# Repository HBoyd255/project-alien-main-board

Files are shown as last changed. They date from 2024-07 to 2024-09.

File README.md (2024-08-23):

# Project A.L.I.E.N. Main Board

<!-- Harry Boyd - hboyd255@gmail.com - 22/07/2024 -->

This is the repository for the main board of Project A.L.I.E.N. (Autonomous
Labyrinth Investigator, Explorer, Navigator).

This project started as a University project for the module
[Robotics Design and Construction](https://www.york.ac.uk/students/studying/manage/programmes/module-catalogue/module/ELE00098H).
To get us started, the University provided us with a main board, called the ARB
(Arduino Robotics Board), which was designed to break out the pins of an Arduino
Nano 33 BLE into connectors that were easier to use. However, when the module
concluded, the University wanted the boards back, so I designed my own.

## Testing

The code to test the board has been split into separate repositories.

- [Motors and Encoders](https://github.com/HBoyd255/project-alien-motor-test-code)
- [Bumper and NES Shift Registers](https://github.com/HBoyd255/project-alien-shift-register-test-code)
- [LED Strip and Level Shifter](https://github.com/HBoyd255/project-alien-led-strip-test-code)
- [Ultrasonic Sensor](https://github.com/HBoyd255/project-alien-ultrasonic-test-code)
- [Infrared Sensors and I2C Multiplexer](https://github.com/HBoyd255/project-alien-infrared-test-code)

## Expansion Boards

The Project A.L.I.E.N. Main Board has been designed to to take expansion boards.
This utilises the 3 left-over GPIO pins, D11, D12 and D13.

- [Extra buttons ](https://github.com/HBoyd255/project-alien-expansion-demo-buttons)

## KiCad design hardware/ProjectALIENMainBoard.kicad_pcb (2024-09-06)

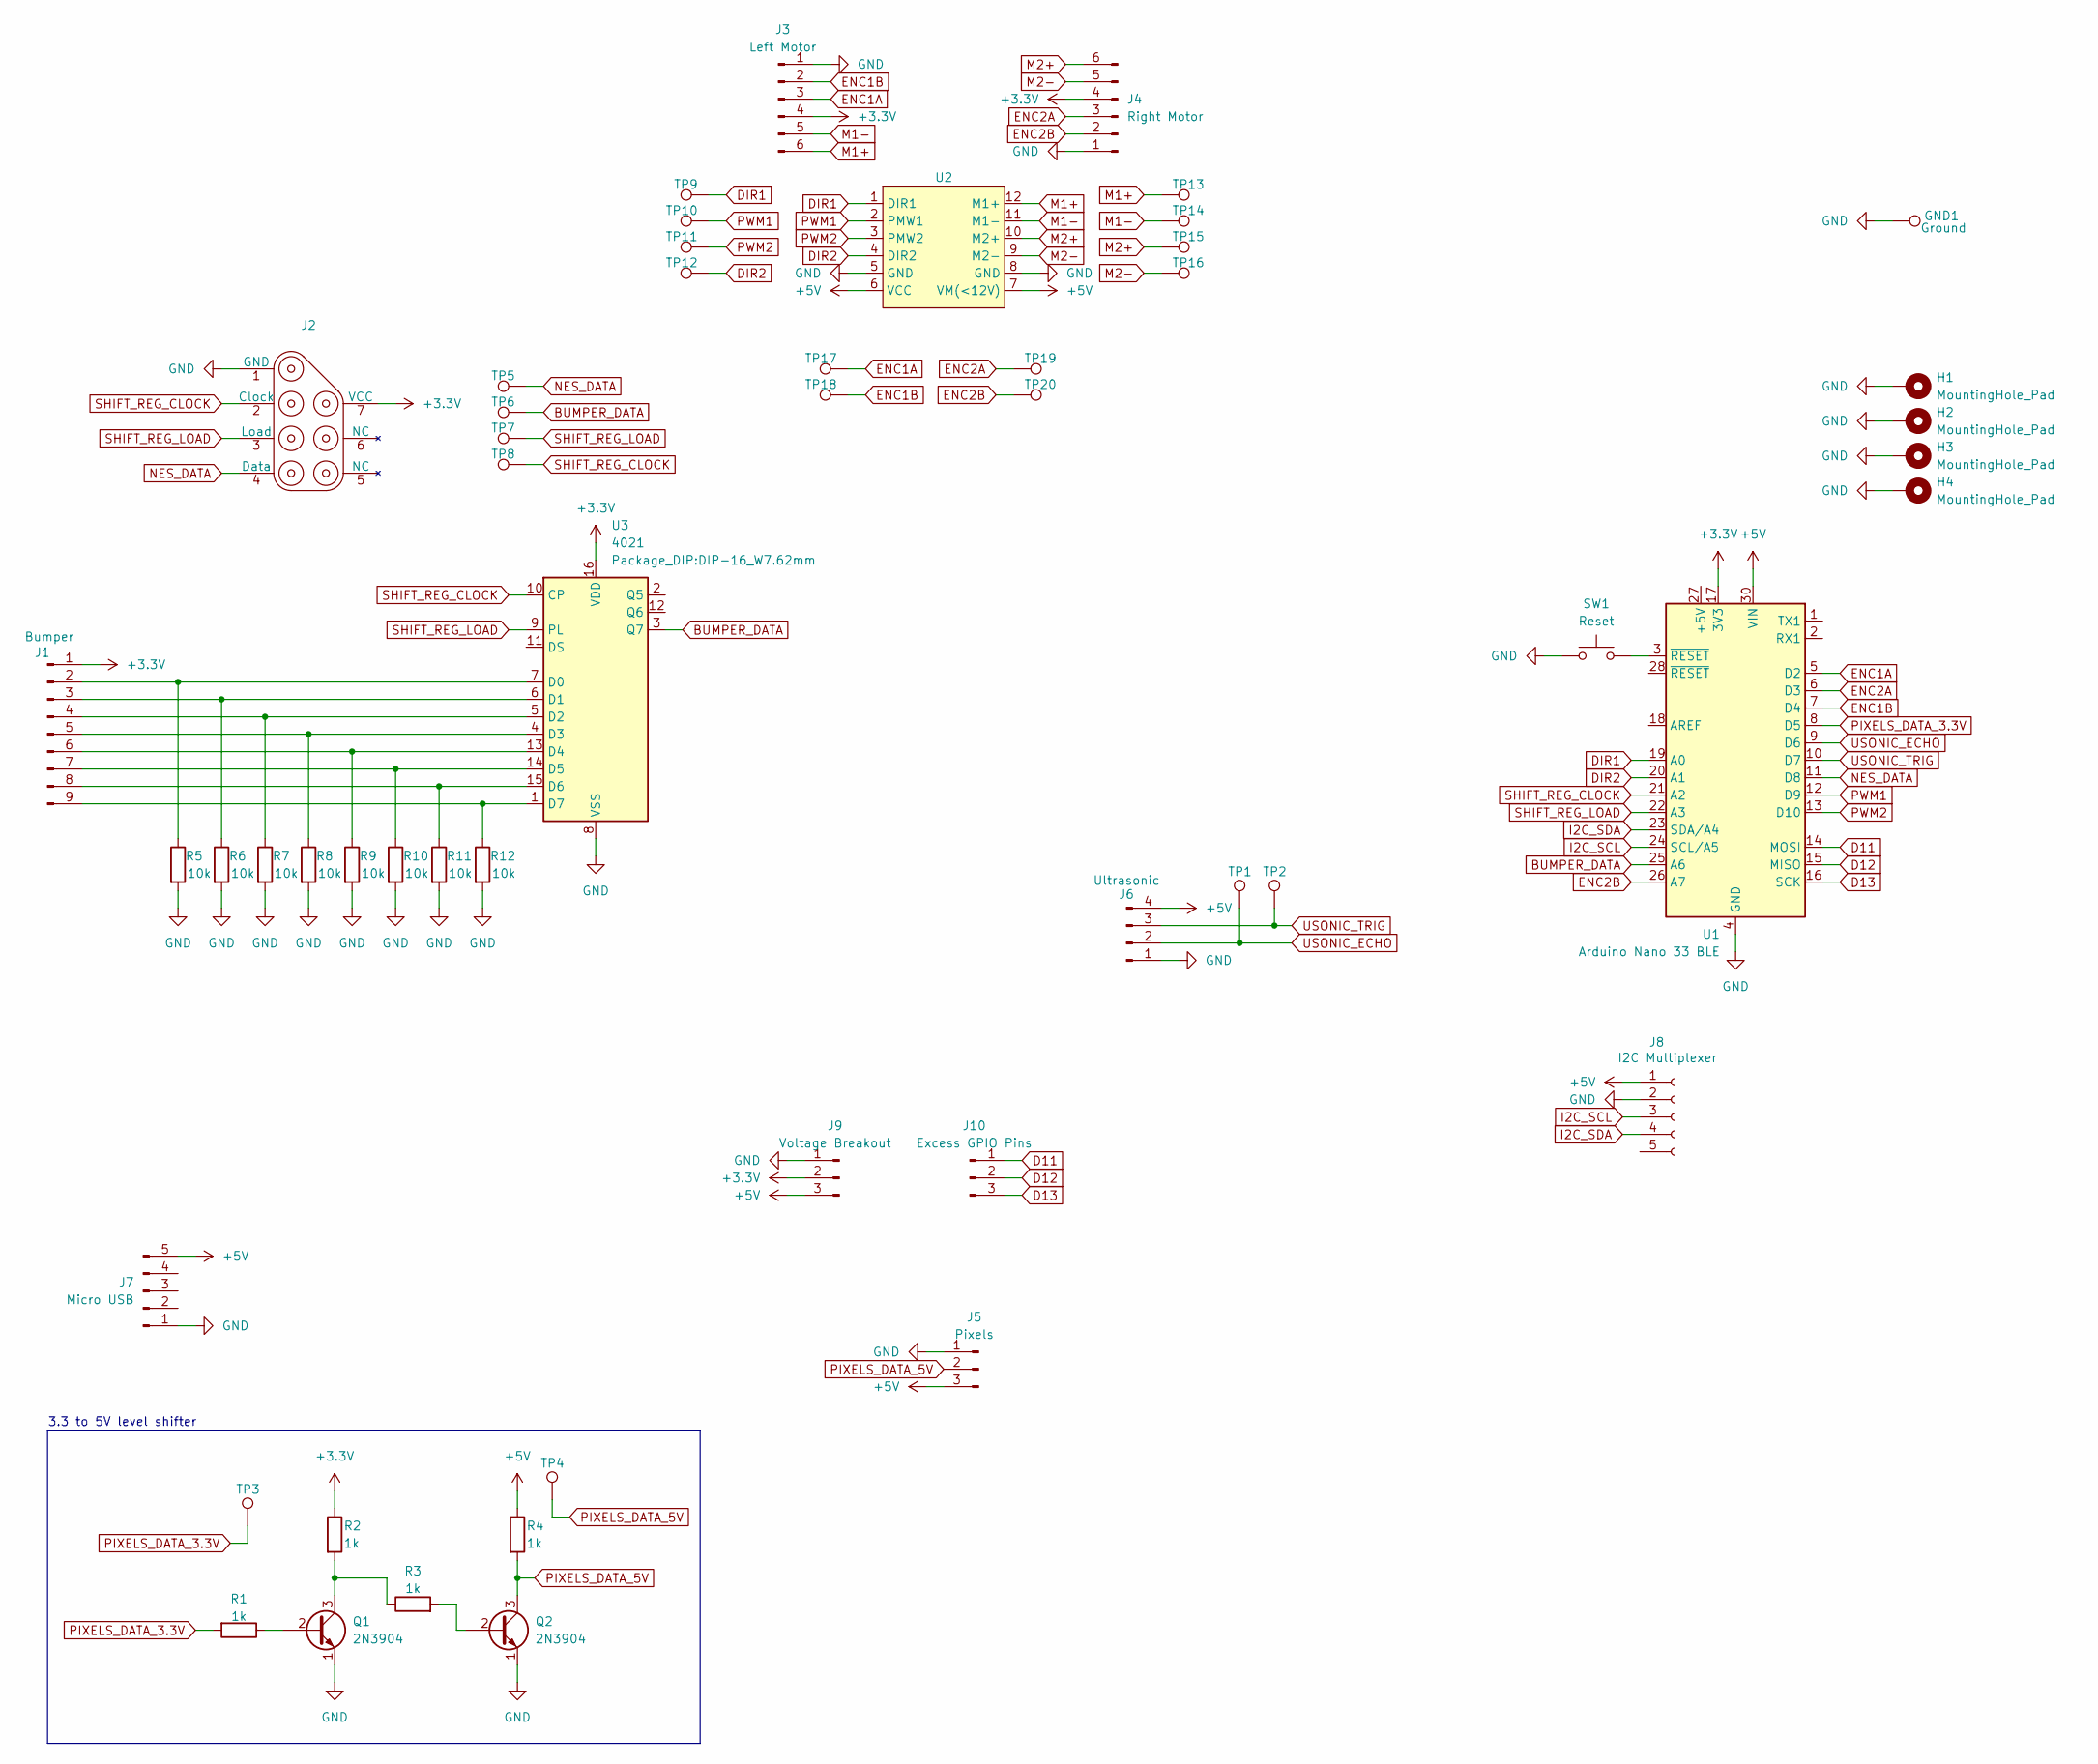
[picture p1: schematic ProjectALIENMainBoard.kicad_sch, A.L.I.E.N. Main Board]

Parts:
GND1: Ground; TestPoint_Bridge_Pitch2.54mm_Drill0.7mm
H1, H2, H3, H4: MountingHole_Pad; MountingHole_2.7mm_M2.5_Pad
J1: Bumper; PinHeader_1x09_P2.54mm_Horizontal
J2: NES_Controller_Port
J3: Left Motor; PinHeader_1x06_P2.54mm_Horizontal
J4: Right Motor; PinHeader_1x06_P2.54mm_Horizontal
J5: Pixels; PinHeader_1x03_P2.54mm_Vertical
J6: Ultrasonic; PinHeader_1x04_P2.54mm_Horizontal
J7: Micro USB; Adafruit_1833_Shield
J8: I2C Multiplexer; Adafruit_5664_Shield
J9: Voltage Breakout; PinHeader_1x03_P2.54mm_Vertical
J10: Excess GPIO Pins; PinHeader_1x03_P2.54mm_Vertical
Q1, Q2: 2N3904; TO-92_Inline
R1, R2, R3, R4: 1k; R_0402_1005Metric_Pad0.72x0.64mm_HandSolder
R5, R6, R7, R8, R9, R10, R11, R12: 10k; R_0402_1005Metric_Pad0.72x0.64mm_HandSolder
SW1: Reset; Two_Pin_Through_Hole_Push_Button
TP1, TP2, TP3, TP4, TP5, TP6, TP7, TP8, TP9, TP10, TP11, TP12, TP13, TP14, TP15, TP16, TP17, TP18, TP19, TP20: TestPoint; TestPoint_THTPad_D1.0mm_Drill0.5mm
U1: Arduino Nano 33 BLE; Arduino_Nano
U2: DFRobot_DC_Motor_Driver_Shield
U3: 4021; DIP-16_W7.62mm

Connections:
+3.3V: J1.1, J2.7 (VCC), J3.4, J4.4, J9.2, R2.1, U1.17 (3V3), U3.16 (VDD)
+5V: J5.3, J6.4, J7.5, J8.1, J9.3, R4.1, U1.30 (VIN), U2.6 (VCC), U2.7 (VM(<12V))
BUMPER_DATA: TP6.1, U1.25 (A6), U3.3 (Q7)
D11: J10.1, U1.14 (MOSI)
D12: J10.2, U1.15 (MISO)
D13: J10.3, U1.16 (SCK)
DIR1: TP9.1, U1.19 (A0), U2.1 (DIR1)
DIR2: TP12.1, U1.20 (A1), U2.4 (DIR2)
ENC1A: J3.3, TP17.1, U1.5 (D2)
ENC1B: J3.2, TP18.1, U1.7 (D4)
ENC2A: J4.3, TP19.1, U1.6 (D3)
ENC2B: J4.2, TP20.1, U1.26 (A7)
GND: GND1.1, H1.1, H2.1, H3.1, H4.1, J2.1 (GND), J3.1, J4.1, J5.1, J6.1, J7.1, J8.2, J9.1, Q1.1 (E), Q2.1 (E), R5.2, R6.2, R7.2, R8.2, R9.2, R10.2, R11.2, R12.2, SW1.1, U1.4 (GND), U1.29 (GND), U2.5 (GND), U2.8 (GND), U3.8 (VSS)
I2C_SCL: J8.3, U1.24 (SCL/A5)
I2C_SDA: J8.4, U1.23 (SDA/A4)
M1+: J3.6, TP13.1, U2.12 (M1+)
M1-: J3.5, TP14.1, U2.11 (M1-)
M2+: J4.6, TP15.1, U2.10 (M2+)
M2-: J4.5, TP16.1, U2.9 (M2-)
NES_DATA: J2.4 (Data), TP5.1, U1.11 (D8)
unnamed: J1.2, R5.1, U3.7 (D0)
unnamed: J1.3, R6.1, U3.6 (D1)
unnamed: J1.4, R7.1, U3.5 (D2)
unnamed: J1.5, R8.1, U3.4 (D3)
unnamed: J1.6, R9.1, U3.13 (D4)
unnamed: J1.7, R10.1, U3.14 (D5)
unnamed: J1.8, R11.1, U3.15 (D6)
unnamed: J1.9, R12.1, U3.1 (D7)
unnamed: Q1.2 (B), R1.1
unnamed: Q1.3 (C), R2.2, R3.1
unnamed: Q2.2 (B), R3.2
unnamed: SW1.2, U1.3 (~RESET)
PIXELS_DATA_3.3V: R1.2, TP3.1, U1.8 (D5)
PIXELS_DATA_5V: J5.2, Q2.3 (C), R4.2, TP4.1
PWM1: TP10.1, U1.12 (D9), U2.2 (PMW1)
PWM2: TP11.1, U1.13 (D10), U2.3 (PMW2)
SHIFT_REG_CLOCK: J2.2 (Clock), TP8.1, U1.21 (A2), U3.10 (CP)
SHIFT_REG_LOAD: J2.3 (Load), TP7.1, U1.22 (A3), U3.9 (PL)
USONIC_ECHO: J6.2, TP1.1, U1.9 (D6)
USONIC_TRIG: J6.3, TP2.1, U1.10 (D7)

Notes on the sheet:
3.3 to 5V level shifter

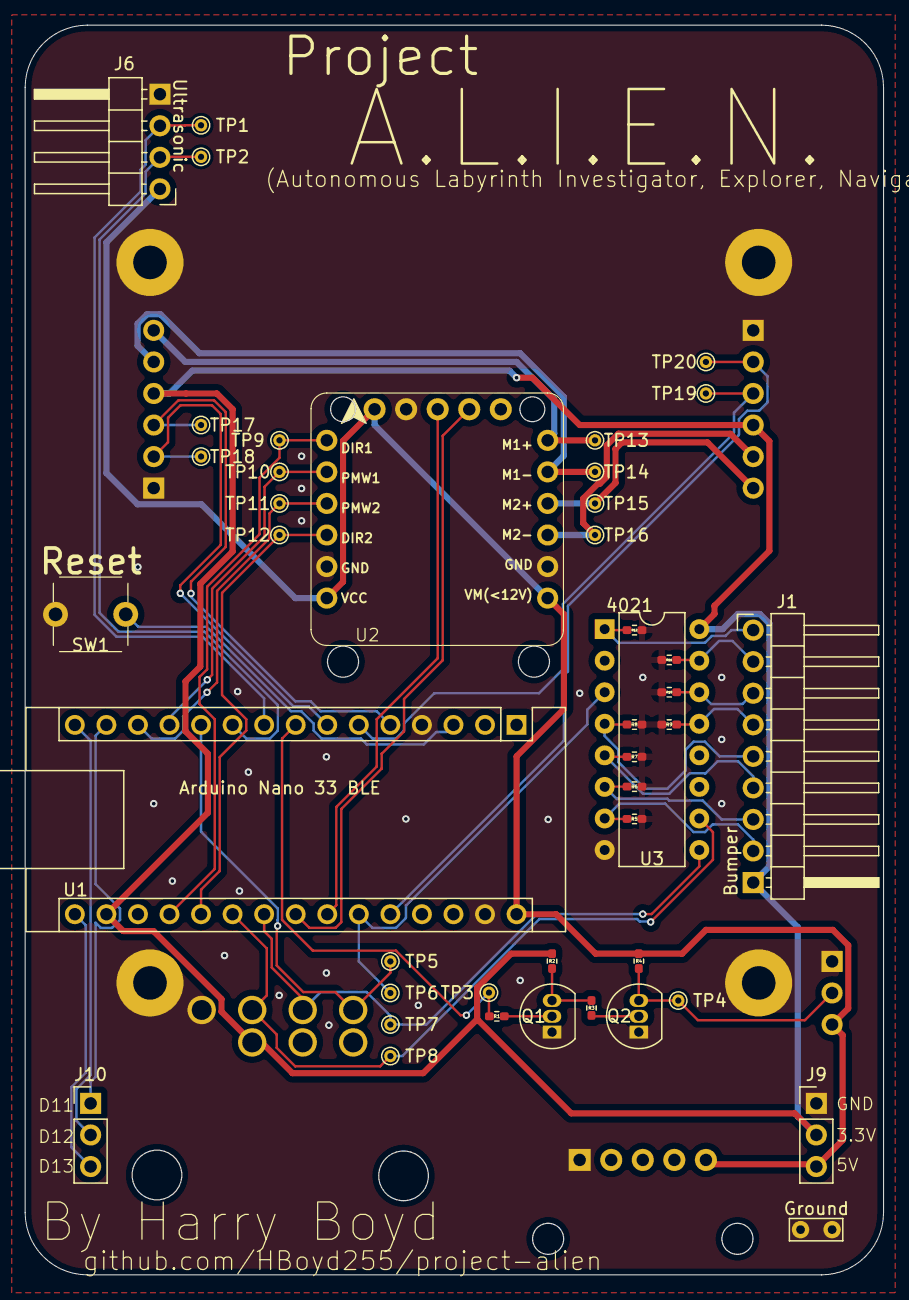
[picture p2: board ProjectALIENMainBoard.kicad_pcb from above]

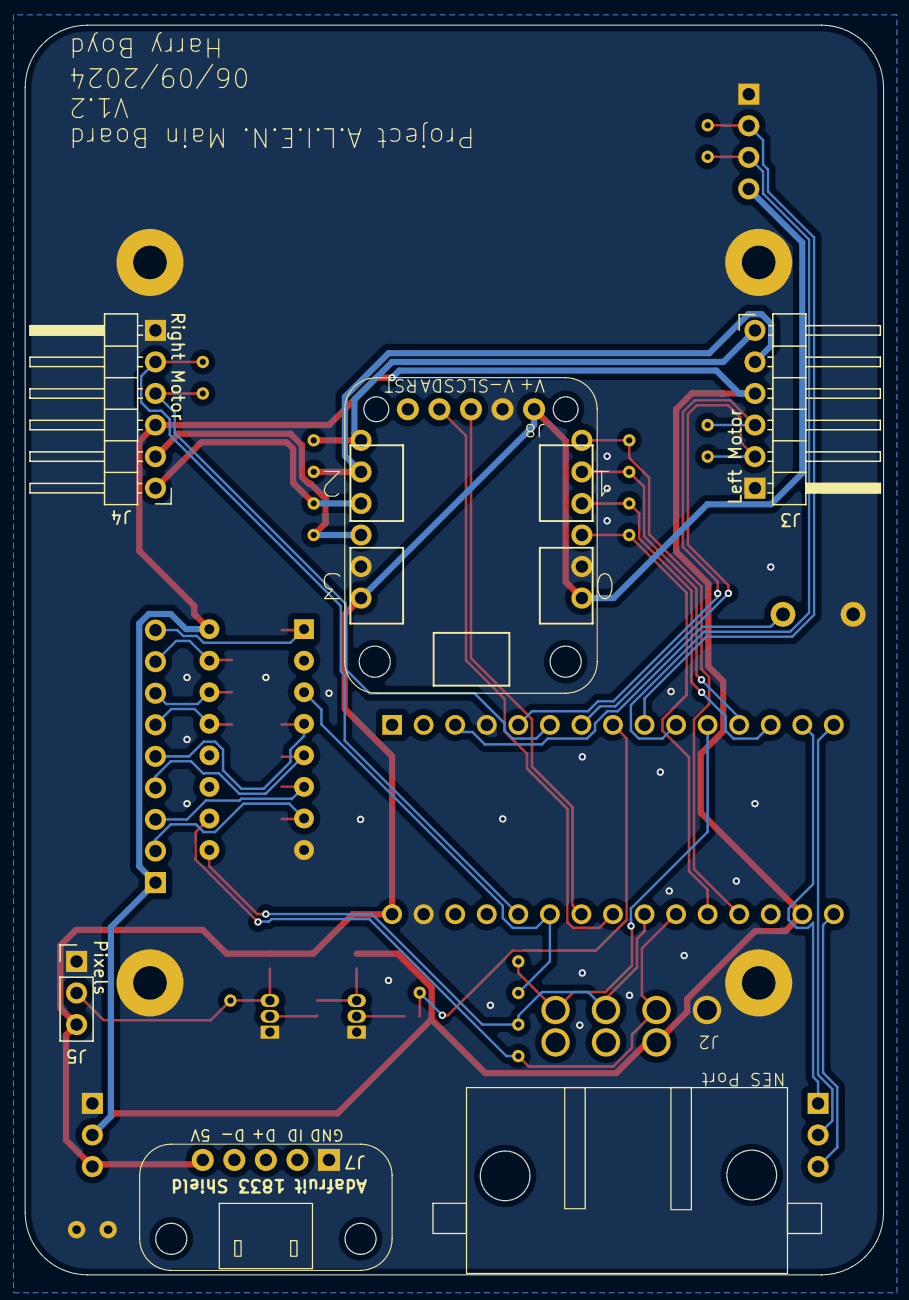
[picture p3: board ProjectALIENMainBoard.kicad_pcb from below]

Board: 2 copper layers, 69.1 x 100.6 mm, 53 parts (6 on the bottom side), 40 nets.

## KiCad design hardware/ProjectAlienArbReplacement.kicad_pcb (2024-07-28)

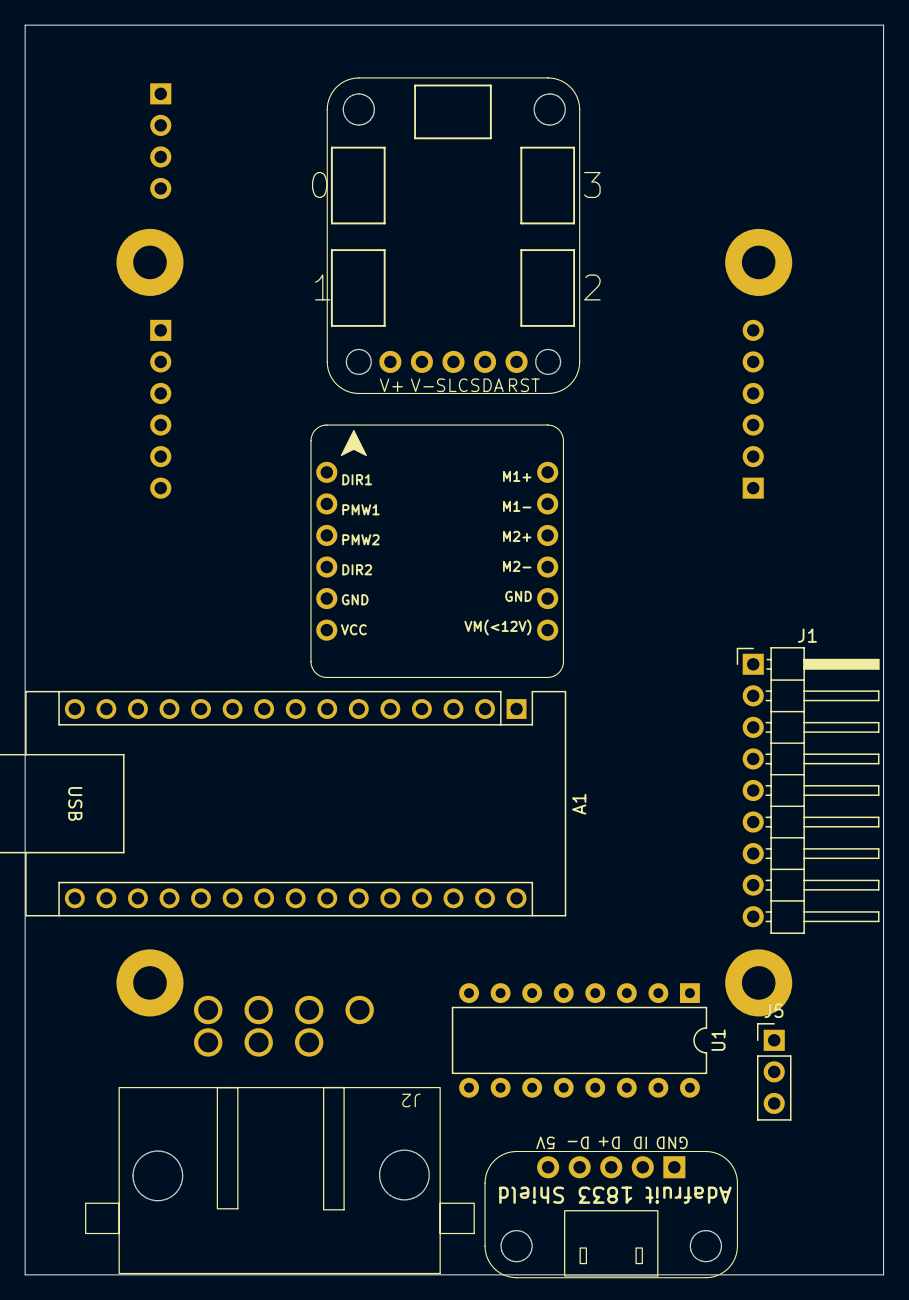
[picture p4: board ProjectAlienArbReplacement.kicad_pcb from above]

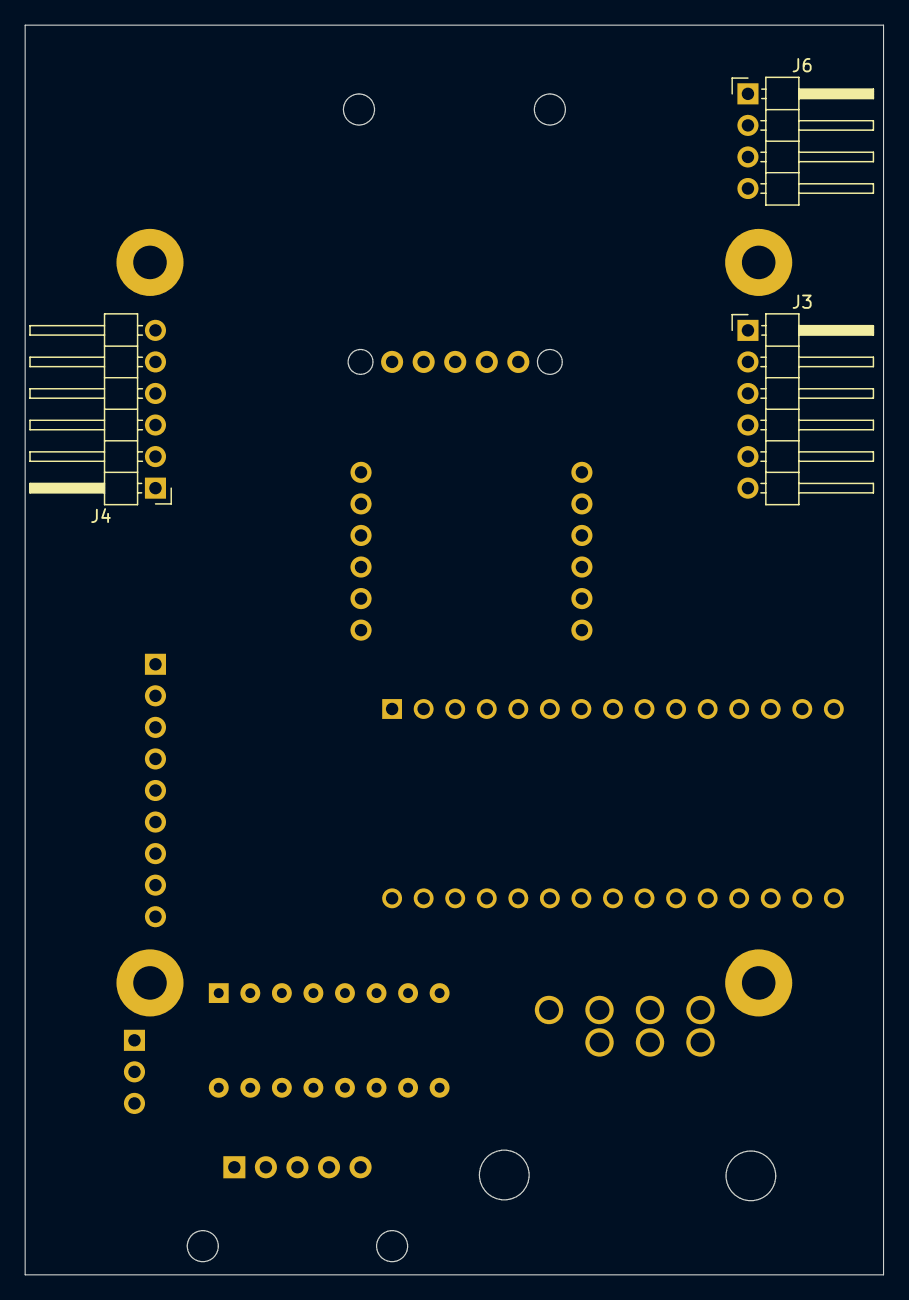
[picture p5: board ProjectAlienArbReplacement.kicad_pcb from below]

Board: 2 copper layers, 69.1 x 100.6 mm, 15 parts (3 on the bottom side), 19 nets, no tracks yet.

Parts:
A1: Arduino_Nano_Every; Arduino_Nano
H1, H2, H3, H4: MountingHole_Pad; MountingHole_2.7mm_M2.5_Pad
J1: Bumper Connector; PinHeader_1x09_P2.54mm_Horizontal
J2: NES_Controller_Port
J3: Left Motor Connector; PinHeader_1x06_P2.54mm_Horizontal
J4: Right Motor Connector; PinHeader_1x06_P2.54mm_Horizontal
J5: Pixels Connector; PinHeader_1x03_P2.54mm_Vertical
J6: Ultrasonic Connector; PinHeader_1x04_P2.54mm_Horizontal
J7: Micro USB; Adafruit_1833_Shield
J8: I2C Multiplexer; Adafruit_5664_Shield
M1: DFRobot_DC_Motor_Driver_Shield
U1: 4021; DIP-16_W7.62mm

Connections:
+5V: J1.1, J2.7 (VCC), U1.16 (VDD)
BUMPER_DATA: A1.25 (A6), U1.11 (DS)
GND: H1.1, H2.1, H3.1, H4.1, J2.1 (GND), M1.5 (GND), M1.8 (GND), U1.8 (VSS)
NES_DATA: A1.11 (D8), J2.4 (Data)
unnamed: A1.19 (A0), M1.1 (DIR1)
unnamed: A1.20 (A1), M1.4 (DIR2)
unnamed: A1.12 (D9), M1.2 (PMW1)
unnamed: A1.13 (D10), M1.3 (PMW2)
unnamed: A1.4 (GND), A1.29 (GND)
unnamed: J1.2, U1.7 (D0)
unnamed: J1.3, U1.6 (D1)
unnamed: J1.4, U1.5 (D2)
unnamed: J1.5, U1.4 (D3)
unnamed: J1.6, U1.13 (D4)
unnamed: J1.7, U1.14 (D5)
unnamed: J1.8, U1.15 (D6)
unnamed: J1.9, U1.1 (D7)
SHIFT_REG_CLOCK: A1.21 (A2), J2.2 (Clock), U1.10 (CP)
SHIFT_REG_LOAD: A1.22 (A3), J2.3 (Load), U1.9 (PL)

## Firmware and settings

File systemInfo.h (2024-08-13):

/**
 * @file systemInfo.h
 * @brief Definition for constant values related to the hardware setup for the
 * Project A.L.I.E.N. robot.
 *
 * @author Harry Boyd - https://github.com/HBoyd255
 * @date 2024-08-13
 * @copyright Copyright (c) 2024
 */

// This is a copy of the pin definitions for the robot.

#ifndef SYSTEM_INFO_H
#define SYSTEM_INFO_H

// Motors
// Left (Motor 1)
#define LEFT_MOTOR_DIRECTION_PIN A0
#define LEFT_MOTOR_SPEED_PIN D9
#define LEFT_MOTOR_ENCODER_A_PIN D2
#define LEFT_MOTOR_ENCODER_B_PIN D4

// Right (Motor 2)
#define RIGHT_MOTOR_DIRECTION_PIN A1
#define RIGHT_MOTOR_SPEED_PIN D10
#define RIGHT_MOTOR_ENCODER_A_PIN D3
#define RIGHT_MOTOR_ENCODER_B_PIN A7

// Shift registers
#define BUMPER_SHIFT_REG_DATA A6
#define NES_SHIFT_REG_DATA D8
#define COMMON_SHIFT_REG_LOAD A3
#define COMMON_SHIFT_REG_CLOCK A2

// Pixels
// The pin that D1 of the LED strip is connected to.
#define PIXELS_DATA_PIN D5
// The number of Ws2812 LEDs on the robot.
#define LED_COUNT 16

// Ultrasonic
#define ULTRASONIC_TRIGGER D7
#define ULTRASONIC_ECHO D6

// Infrared
#define LEFT_INFRARED_INDEX 0
#define RIGHT_INFRARED_INDEX 1
#define FRONT_LEFT_INFRARED_INDEX 2
#define FRONT_RIGHT_INFRARED_INDEX 3
#endif  // SYSTEM_INFO_H

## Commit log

2024-07-22 Created empty kicad project
    [ProjectAlienArbReplacement.kicad_pcb, ProjectAlienArbReplacement.kicad_sch]
2024-07-23 Placed first draft of connectors
    [ProjectAlienArbReplacement.kicad_pcb, ProjectAlienArbReplacement.kicad_sch]
2024-07-28 Added I2C multiplexer
    [ProjectAlienArbReplacement.kicad_pcb, ProjectAlienArbReplacement.kicad_sch]
2024-07-28 Added motor driver
    [ProjectAlienArbReplacement.kicad_pcb, ProjectAlienArbReplacement.kicad_sch]
2024-07-28 Fixed screw hole size
    [ProjectAlienArbReplacement.kicad_pcb]
2024-07-28 Updated pcb boarder
    [ProjectAlienArbReplacement.kicad_pcb]
2024-07-28 Plated mount holes
    [ProjectAlienArbReplacement.kicad_pcb]
2024-08-13 Updated name to Project A.L.I.E.N. Main Board
    [ProjectAlienArbReplacement.kicad_sch, ProjectAlienMainBoard.kicad_pcb, ProjectAlienMainBoard.kicad_sch]
2024-08-13 Swapped resistors for SMT
    [ProjectAlienMainBoard.kicad_pcb, ProjectAlienMainBoard.kicad_sch]
2024-08-14 Routed Tracks
    [ProjectAlienMainBoard.kicad_pcb, ProjectAlienMainBoard.kicad_sch]
2024-08-14 Added ground plane
    [ProjectAlienMainBoard.kicad_pcb, ProjectAlienMainBoard.kicad_sch]
2024-08-14 Fixed all errors
    [ProjectAlienMainBoard.kicad_pcb]
2024-08-14 Finished component silkscreen labels
    [ProjectAlienMainBoard.kicad_pcb, ProjectAlienMainBoard.kicad_sch]
2024-08-14 Updated text
    [ProjectAlienMainBoard.kicad_pcb]
2024-08-14 Added title to PCB
    [ProjectAlienMainBoard.kicad_pcb]
2024-08-15 Increased size of name
    [ProjectAlienMainBoard.kicad_pcb]
2024-08-15 Tweaked silkscreen
    [ProjectAlienMainBoard.kicad_pcb, ProjectAlienMainBoard.kicad_sch]
2024-08-15 Generated gerber version 1
    [ProjectAlienMainBoard-B_Cu.gbr, ProjectAlienMainBoard-B_Mask.gbr, ProjectAlienMainBoard-B_Paste.gbr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]
2024-08-16 Capitalised ALIEN
    [ProjectAlienMainBoard-B_Cu.gbr, ProjectAlienMainBoard-B_Mask.gbr, ProjectAlienMainBoard-B_Paste.gbr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]
2024-08-16 Changing name capitalisation
    [rojectALIENMainBoard-B_Cu.gbr, rojectALIENMainBoard-B_Mask.gbr, rojectALIENMainBoard-B_Paste.gbr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]
2024-08-16 Changed name capitalisation
    [ProjectALIENMainBoard-B_Cu.gbr, ProjectALIENMainBoard-B_Mask.gbr, ProjectALIENMainBoard-B_Paste.gbr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]
2024-08-23 Added Expansion Boards to README.md
    [ProjectALIENMainBoard.kicad_pcb]
2024-08-23 Added board into to silkscreen (V1.0)
    [ProjectALIENMainBoard-B_Cu.gbr, ProjectALIENMainBoard-B_Mask.gbr, ProjectALIENMainBoard-B_Paste.gbr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]
2024-08-23 Added labels to Pixels connector
    [ProjectALIENMainBoard.kicad_pcb]
2024-08-23 Tidied up traces
    [ProjectALIENMainBoard.kicad_pcb]
2024-08-24 Fixed direction of connectors
    [ProjectALIENMainBoard.kicad_pcb, ProjectALIENMainBoard.kicad_sch]
2024-08-24 Fixed connector Issues
    [ProjectALIENMainBoard.kicad_pcb]
2024-08-24 Updated designators
    [ProjectALIENMainBoard.kicad_pcb, ProjectALIENMainBoard.kicad_sch]
2024-08-24 Updated labels for pixels
    [ProjectALIENMainBoard.kicad_pcb]
2024-08-24 Moved pixels labels again
    [ProjectALIENMainBoard.kicad_pcb]
2024-08-24 Generated gerber files (V1.1)
    [ProjectALIENMainBoard-B_Cu.gbr, ProjectALIENMainBoard-B_Mask.gbr, ProjectALIENMainBoard-B_Paste.gbr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]
2024-09-06 Flipped and repositioned motor connectors
    [ProjectALIENMainBoard.kicad_pcb]
2024-09-06 Generated v1.2 gerber
    [ProjectALIENMainBoard-B_Cu.gbr, ProjectALIENMainBoard-B_Mask.gbr, ProjectALIENMainBoard-B_Paste.gbr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]
